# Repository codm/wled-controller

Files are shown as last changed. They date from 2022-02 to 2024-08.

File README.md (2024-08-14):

# cod.m WLED Controller (Wi-FI/WLAN)

ESP32 based WLED Controller Wi-Fi to drive adressable LED strips like Neopixel/WS281x/SK6812/WS2801/WS2815/etc using [WLED](https://github.com/Aircoookie/WLED).
Version 0.8 now can be used with 5V *and* 12V strips without the need of external dc-dc converters and we've updated the microcontroller from an ESP8266 to an ESP32. Therefore handling of more LED's and multiple strips are no problem. See https://kno.wled.ge/features/multi-strip/

There now is a button (`IO15`) which can be freely confirugred via WLED. See https://kno.wled.ge/features/macros/#buttons Theoreticly you can also use the flash button on the PCB as an input (`IO0`).

As of WLED 0.13 the first button can be used to do a factory reset by holding it for longer than ten seconds.

* [Wiring Example WS281x/SK6812 5V/12V/24V](https://shop.codm.de/media/e0/8c/7e/1694690940/wiring-scheme-wled-controller-V0.8-WS281x-SK6812.pdf)
* [Wiring Example WS2801/APA102 5V/12V/24V](https://shop.codm.de/media/15/71/33/1694690940/wiring-scheme-wled-controller-V0.8-WS2801.pdf)
* [Wiring Example WS2815 12V](https://shop.codm.de/media/7c/08/47/1694690940/wiring-scheme-wled-controller-V0.8-WS2815.pdf)

More documentation could be foun in the [cod.m Knowledge Base: WLED Controller](https://docs.codm.de/en/wled/controller/).

You can buy it at our webshop: 
* [WLED Controller (Wi-Fi)](https://shop.codm.de/en/automation/wled/30/wled-controller-wlan/wi-fi) (English)
* [WLED Controller (WLAN)](https://shop.codm.de/automation/pixel/30/wlan-pixel-controller-wled) (German)

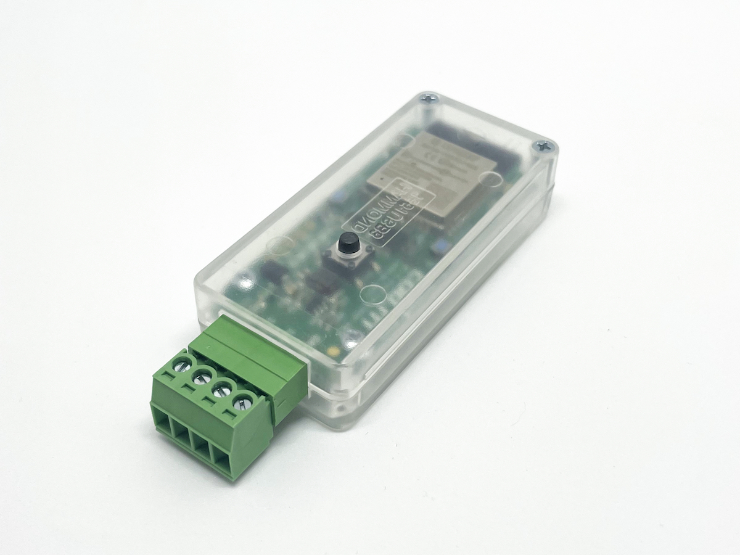
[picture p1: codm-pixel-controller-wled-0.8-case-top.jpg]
cod.m GmbH WLED Controller (Wi-Fi/WLAN) (https://shop.codm.de/automation/wled/30/wled-controller-wlan/wi-fi)


The board comes preflashed with the current version of WLED, but can be used with any firmware you like, as we've added a flash and reset button for easy flashing.

It can be used with nearly every type of adressable led strips: WS2812B, WS2813, SK6812, APA102, WS2801, LPD8806, TM1814, WS2811, WS2815, GS8208.

Please read the [Adafruit Neopixel Uberguide](https://learn.adafruit.com/adafruit-neopixel-uberguide) on how to work with Neopixels. Antother good starting pint is the [WLED documentation](https://kno.wled.ge/).

Based on the LoxPixel-idea from Dennis (www.unser-smartes-zuhause.de) we've discussed a board layout and in the beginning developed our own software based in Dennis' initial code.
In the end we've settled to expand the absolutely astonishing WLED project with the needed features for Loxone. In Version 0.11 WLED can now understand Loxone values.

## Features

* Espressif ESP32-WROOM-32E 4MB
* usable in 5V, 12V and 24V installations
* up to four lanes of pixel
* drives up to 1000 pixel per lane
* more ESP32 pins are accesible on the back of the PCB
* compact (72x30x16mm)
* reverse polarity protection
* wiring through srew-plug terminal
* real 74AHCT125D level shifter
* detailed instructions
* could be easily (re-)programmed
* open source (CC-BY-NC-SA 4.0)

# Thanks

* [Aircookie](https://github.com/Aircoookie) and the folks from [WLED](https://github.com/Aircoookie/WLED)
* Dennis Henning for the inital idea of the [Lox!Pixel](https://unser-smartes-zuhause.de/2019/10/20/loxpixel-rgbw-neopixel-integration-in-loxone/)
* [m0fa](https://github.com/m0fa)

# License

[CC-BY-NC-SA 4.0](https://creativecommons.org/licenses/by-nc-sa/4.0/de/)

cod.m GmbH, Patrik Mayer, 2022

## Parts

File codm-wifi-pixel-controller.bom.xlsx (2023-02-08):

WLED Controller V0.8
Qty | Value | Device | Package | Parts | Description
2 |  | 434153017835 | 434153017835 | FLASH, RESET | WS-TASV J-Bend SMT Tact Switch 3.5x2.9 mm
1 |  | PINHD-1X5 | 1X05 | JP1 | PIN HEADER
4 | 100n | C-EUC0603K | C0603K | C2, C3, C6, C11 | CAPACITOR, European symbol
2 | 10k | R-EU_R0603 | R0603 | R4, R5 | RESISTOR, European symbol
1 | 10u | C-EUC0805K | C0805K | C1 | CAPACITOR, European symbol
1 | 150080RS75000 | LEDCHIP-LED0805 | CHIP-LED0805 | LED | LED
1 | 1u | C-EUC0603K | C0603K | C5 | CAPACITOR, European symbol
3 | 2.2uF | C-EUC0603K | C0603K | C8, C9, C10 | CAPACITOR, European symbol
1 | 22k1 | R-EU_R0603 | R0603 | R2 | RESISTOR, European symbol
2 | 22uF/6.3V/20% | C-EUC0805K | C0805K | C4, C7 | CAPACITOR, European symbol
1 | 24V 500mA | PTCFUSE-1206 | R1206 | F1 | PTC fuses, resettable thermistors
1 | 2k7 | R-EU_R0603 | R0603 | R3 | RESISTOR, European symbol
1 | 3.3uH | WE-LQ_1812_744045003 | WE-LQ_1812 | L1 | WE-LQ SMD Inductor
1 | 330 | 4R-NEXB38V | EXB38V | RN1 | Array Chip Resistor
1 | 430182070816 | 430182070816 | 430182070816 | S1 | WS-TASV SMT Tact Switch 6x6 mm
1 | 69k8 | R-EU_R0603 | R0603 | R1 | RESISTOR, European symbol
1 | AP62XXX-TSOT26 | AP62XXX-TSOT26 | AP62XXX-TSOT26 | U1
1 | ESP-WROOM-32 | ESP-WROOM-32 | ESP-WROOM-32 | U4
1 | MCV-1,5/4-G-3,81 | MCV-1,5/4-G-3,81 | MCV-1,5/4-G-3,81 | U$101
1 | REG710NA-5/250 | REG710NA-5/250 | SOT95P280X145-6N | U2 | Check prices
1 | SK34A | DIODE-DO214AC | DO214AC | D1 | DIODE
1 | SN74AHCT125PWR | SN74AHCT125PWR | SOP65P640X120-14N | U3 | Check availability

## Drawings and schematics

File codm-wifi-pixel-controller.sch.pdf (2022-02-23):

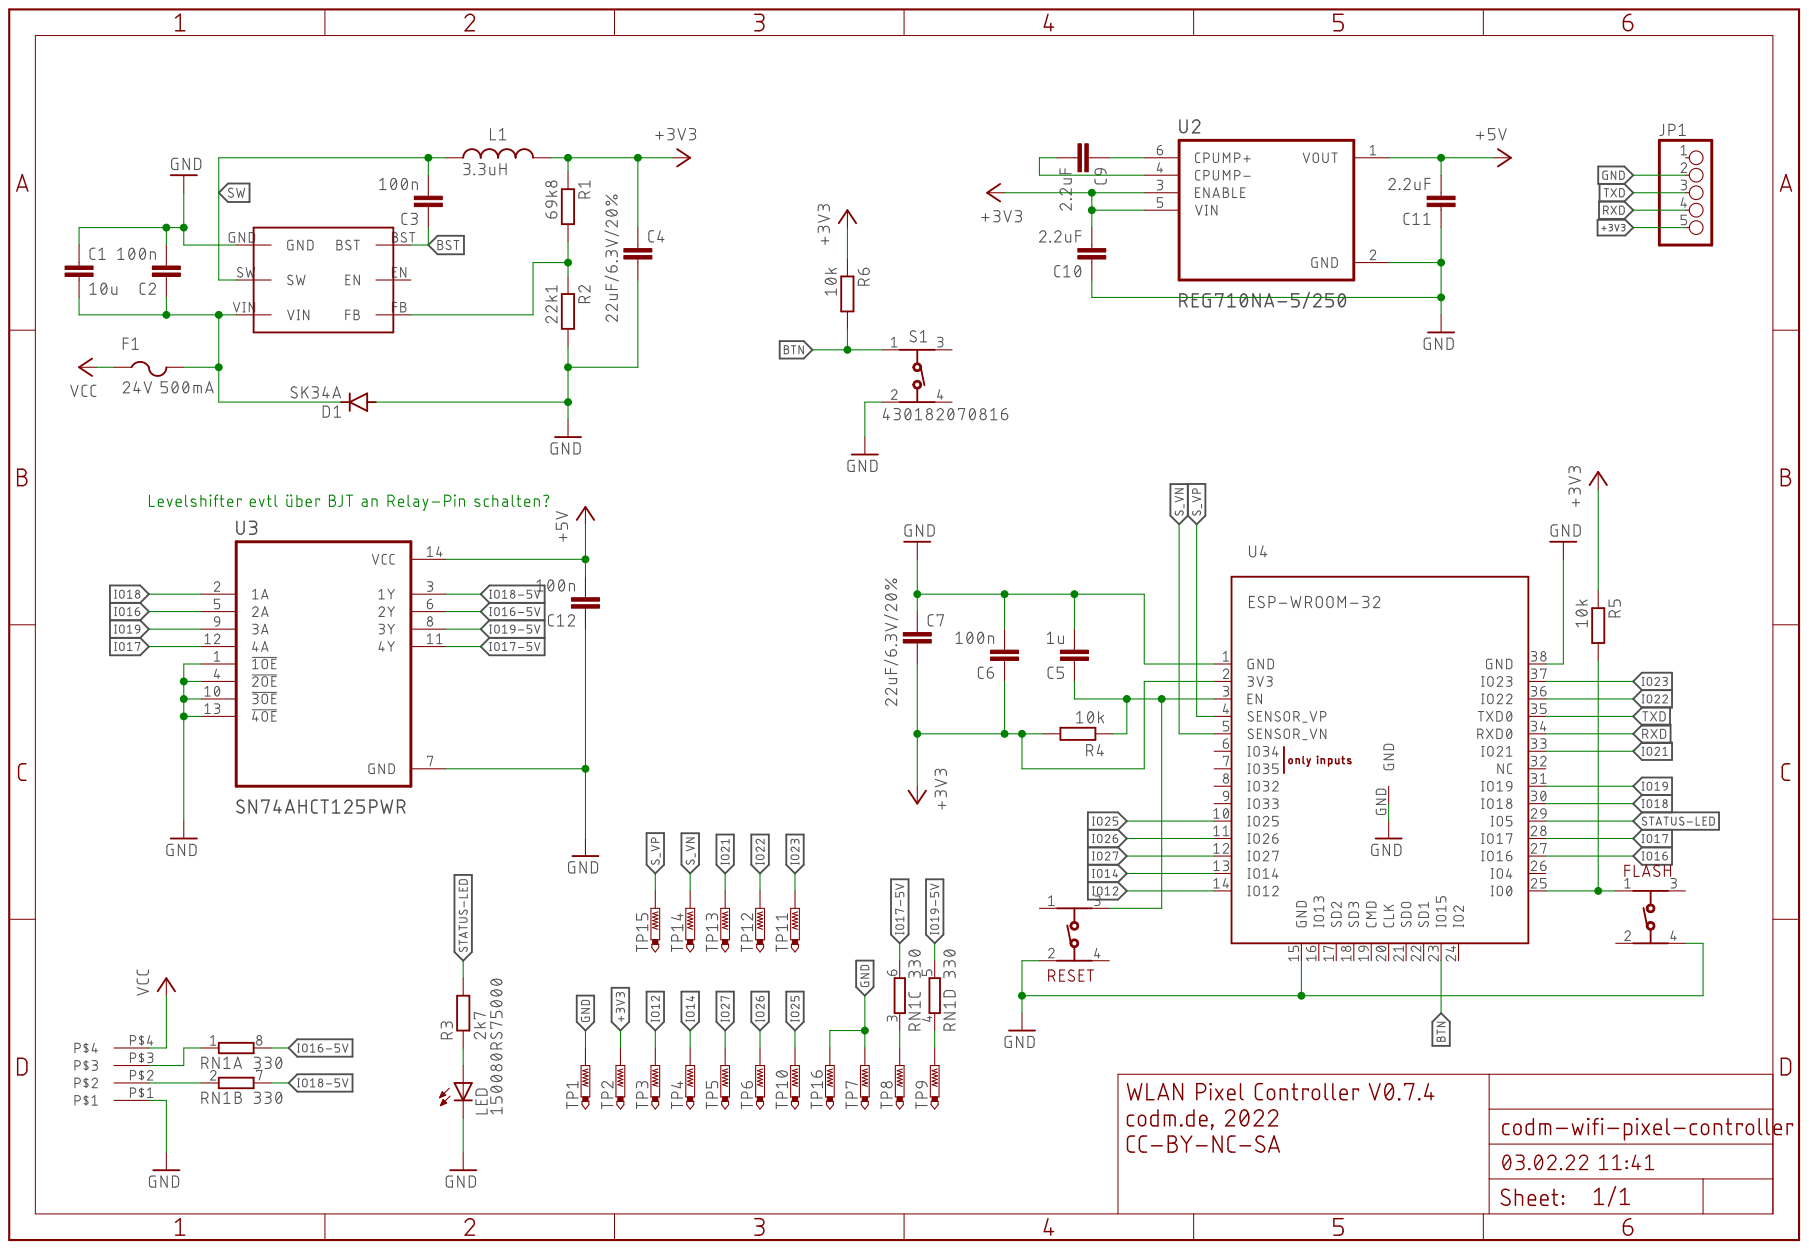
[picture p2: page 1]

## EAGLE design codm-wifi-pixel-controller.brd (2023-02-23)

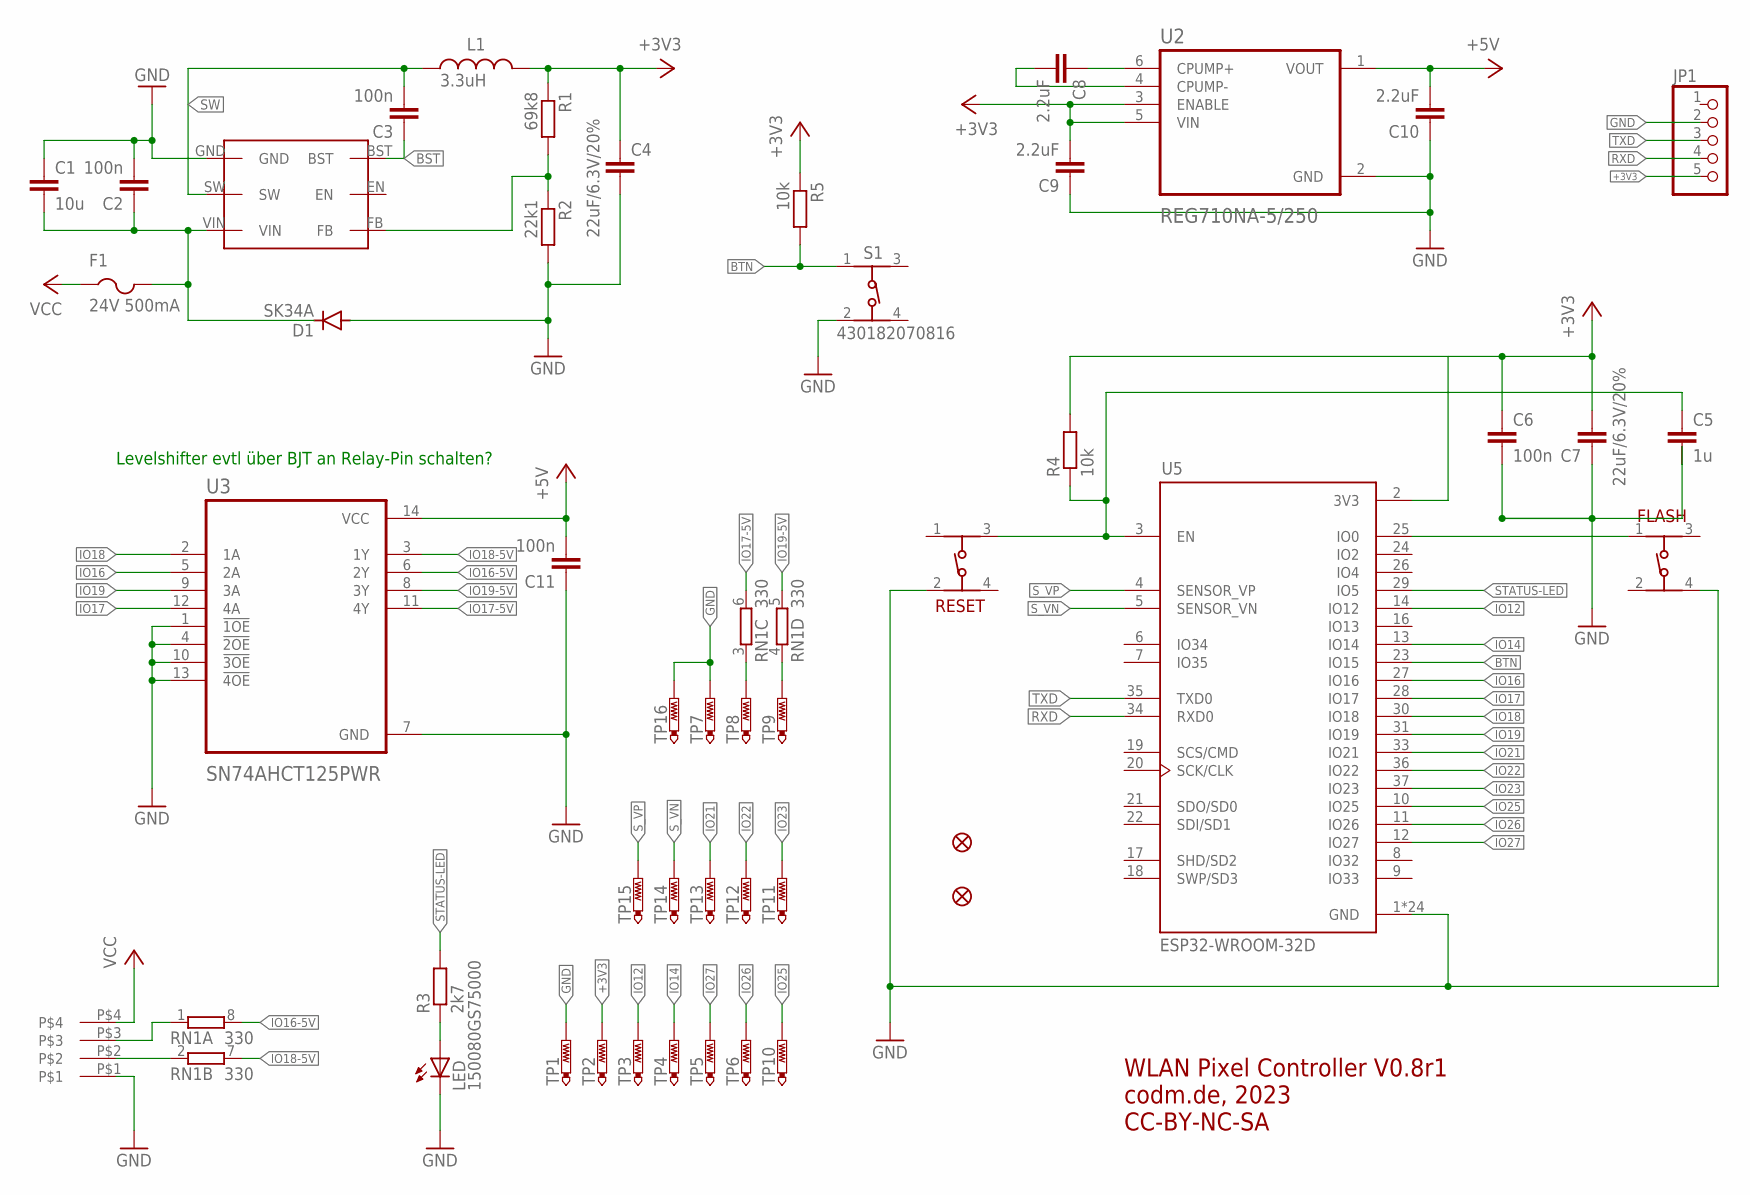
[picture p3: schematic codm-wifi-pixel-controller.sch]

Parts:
C1: 10u; C0805K
C2, C3, C6, C11: 100n; C0603K
C4, C7: 22uF/6.3V/20%; C0805K
C5: 1u; C0603K
C8, C9, C10: 2.2uF; C0603K
D1: SK34A; DO214AC
F1: 24V 500mA; R1206
FD1, FD2: FIDUCIAL1X2; FIDUCIAL-1X2
FLASH: 434153017835
JP1: PINHD-1X5; 1X05
L1: 3.3uH; WE-LQ_1812
LED: 150080GS75000; CHIP-LED0805
R1: 69k8; R0603
R2: 22k1; R0603
R3: 2k7; R0603
R4, R5: 10k; R0603
RESET: 434153017835
RN1: 330; EXB38V
S1: 430182070816
TP1, TP2, TP3, TP4, TP5, TP6, TP7, TP8, TP9, TP10, TP11, TP12, TP13, TP14, TP15, TP16: PTR1TP14R; TP14R
U1: AP62XXX-TSOT26
U2: REG710NA-5/250; SOT95P280X145-6N
U3: SN74AHCT125PWR; SOP65P640X120-14N
U5: ESP32-WROOM-32D; MODULE_ESP32-WROOM-32D
U$101: MCV-1,5/4-G-3,81

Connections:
+3V3: C4.1, C6.1, C7.2, C9.2, JP1.5, L1.2, R1.1, R4.2, R5.1, TP2.TP, U2.3 (ENABLE), U2.5 (VIN), U5.2 (3V3)
+5V: C10.2, C11.2, U2.1 (VOUT), U3.14 (VCC)
BST: C3.1, U1.BST
BTN: R5.2, S1.1, U5.23 (IO15)
GND: C1.1, C2.2, C4.2, C5.2, C6.2, C7.1, C9.1, C10.1, C11.1, D1.A, FLASH.4, JP1.2, LED.C, R2.2, RESET.2 (3), S1.2, TP1.TP, TP7.TP, TP16.TP, U1.GND, U2.2 (GND), U3.1 (!1OE), U3.4 (!2OE), U3.7 (GND), U3.10 (!3OE), U3.13 (!4OE), U5.1 (GND), U5.15 (GND), U5.38 (GND), U5.39_1 (GND), U5.39_2 (GND), U5.39_3 (GND), U5.39_4 (GND), U5.39_5 (GND), U5.39_6 (GND), U5.39_7 (GND), U5.39_8 (GND), U5.39_9 (GND), U5.39_10 (GND), U5.39_11 (GND), U5.39_12 (GND), U5.39_13 (GND), U5.39_14 (GND), U5.39_15 (GND), U5.39_16 (GND), U5.39_17 (GND), U5.39_18 (GND), U5.39_19 (GND), U5.39_20 (GND), U5.39_21 (GND), U$101.P$1
GPIO0: FLASH.1, U5.25 (IO0)
IO12: TP3.TP, U5.14 (IO12)
IO14: TP4.TP, U5.13 (IO14)
IO16: U3.5 (2A), U5.27 (IO16)
IO16-5V: RN1.8 (2), U3.6 (2Y)
IO16-5VR: RN1.1, U$101.P$3
IO17: U3.12 (4A), U5.28 (IO17)
IO17-5V: RN1.6 (2), U3.11 (4Y)
IO17-5VR: RN1.3 (1), TP8.TP
IO18: U3.2 (1A), U5.30 (IO18)
IO18-5V: RN1.7 (2), U3.3 (1Y)
IO18-5VR: RN1.2 (1), U$101.P$2
IO19: U3.9 (3A), U5.31 (IO19)
IO19-5V: RN1.5 (2), U3.8 (3Y)
IO19-5VR: RN1.4 (1), TP9.TP
IO21: TP13.TP, U5.33 (IO21)
IO22: TP12.TP, U5.36 (IO22)
IO23: TP11.TP, U5.37 (IO23)
IO25: TP10.TP, U5.10 (IO25)
IO26: TP6.TP, U5.11 (IO26)
IO27: TP5.TP, U5.12 (IO27)
unnamed: C8.1, U2.6 (CPUMP+)
unnamed: R1.2, R2.1, U1.FB
unnamed: LED.A, R3.1
unnamed: C8.2, U2.4 (CPUMP-)
RESET: C5.1, R4.1, RESET.3 (2), U5.3 (EN)
RXD: JP1.4, U5.34 (RXD0)
STATUS-LED: R3.2, U5.29 (IO5)
SW: C3.2, L1.1, U1.SW
S_VN: TP14.TP, U5.5 (SENSOR_VN)
S_VP: TP15.TP, U5.4 (SENSOR_VP)
TXD: JP1.3, U5.35 (TXD0)
VCC: F1.1, U$101.P$4
VCCF: C1.2, C2.1, D1.C, F1.2, U1.VIN

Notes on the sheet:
WLAN Pixel Controller V0.8r1 codm.de, 2023 CC-BY-NC-SA
Levelshifter evtl über BJT an Relay-Pin schalten?

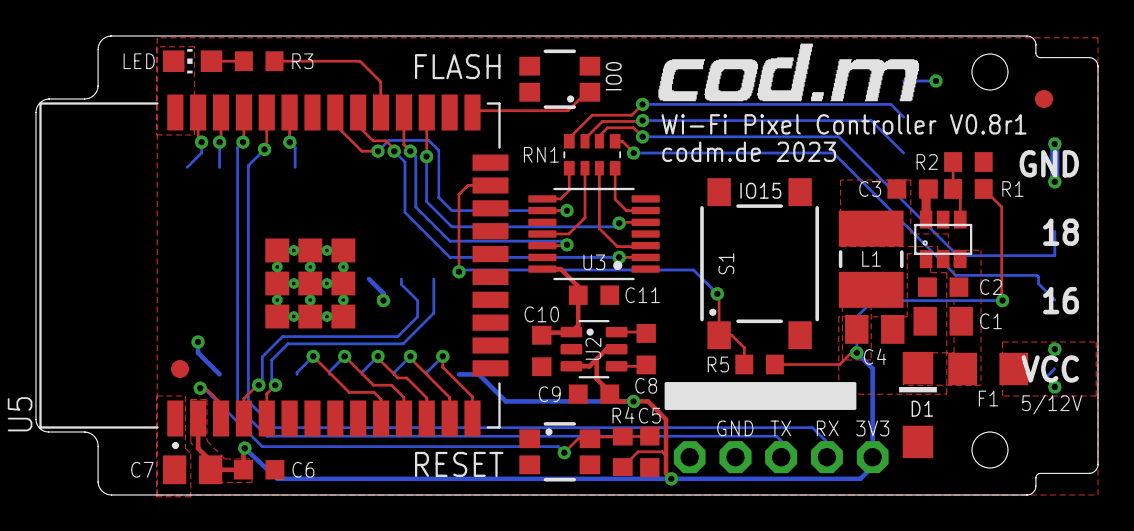
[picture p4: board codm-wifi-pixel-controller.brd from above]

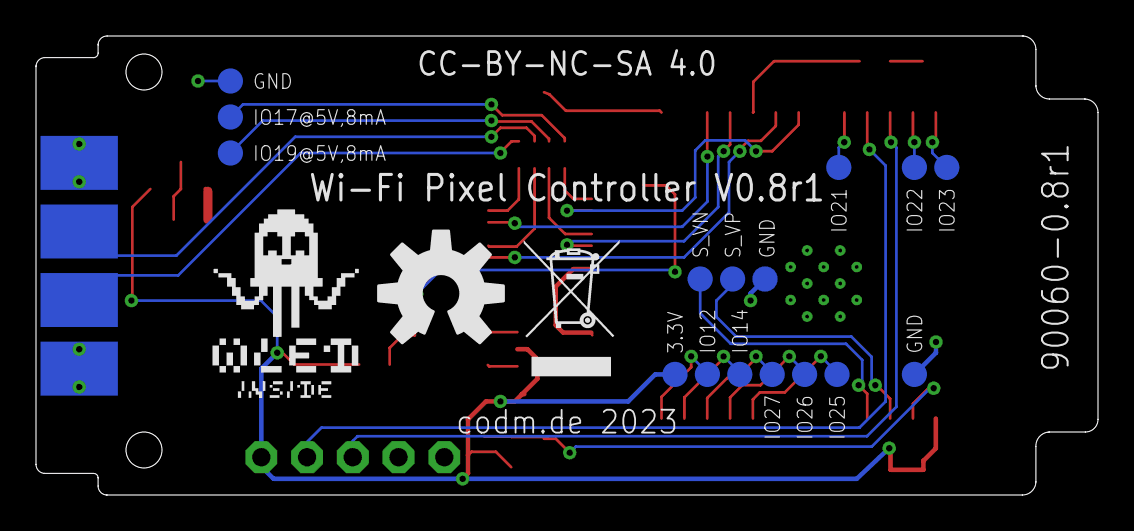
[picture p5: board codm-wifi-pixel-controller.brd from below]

Board: 2 copper layers, 59.0 x 25.5 mm, 52 parts (20 on the bottom side), 39 nets.

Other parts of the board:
U$1: CODM-LOGO
U$2: WLED-INSIDE-LOGO-10MM
U$100: WEEE-LOGO-5MM
U$102: OSHW-LOGO-L

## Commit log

2020-08-11 v 0.4, initial git
    [neopixel-controller-bom.csv, neopixel-controller-bom.xlsx, neopixel-controller.brd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]
2020-09-03 changed 3d model
    [neopixel-controller.brd, neopixel-controller.sch]
2020-09-10 added 74ahct125, rework for v0.5
    [neopixel-controller.brd, neopixel-controller.sch]
2020-09-17 v0.5 pr
    [neopixel-controller.brd, neopixel-controller.sch]
2020-10-26 fixed OE of 74AHCT125
    [neopixel-controller.brd, neopixel-controller.sch]
2020-11-23 minor changes in schematic
    [neopixel-controller-bom.csv, neopixel-controller-bom.xlsx, neopixel-controller.sch]
2020-11-23 added readme, initial github release
    [codm-wifi-pixel-controller.brd, codm-wifi-pixel-controller.sch]
2021-04-12 v0.6 with placeholder for pick&place
    [codm-wifi-pixel-controller.brd, neopixel-controller-bom.csv, neopixel-controller-bom.xlsx]
2021-10-04 development version 0.7
    [codm-wifi-pixel-controller.brd, neopixel-controller-bom.csv]
2021-10-06 version with TLV767 and bigger thermal via/planes
    [codm-wifi-pixel-controller.brd, codm-wifi-pixel-controller.sch]
2021-10-29 prototype 0.7.2
    [codm-wifi-pixel-controller.brd, codm-wifi-pixel-controller.sch]
2022-01-24 V0.7.3 - forgot reverse polarity protection
    [codm-wifi-pixel-controller.bom.xlsx, codm-wifi-pixel-controller.brd, codm-wifi-pixel-controller.sch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]
2022-01-24 added reverse polarity protection
    [codm-wifi-pixel-controller.brd, codm-wifi-pixel-controller.sch]
2022-02-02 new version 0.7.4 with fixes
    [codm-wifi-pixel-controller.brd, codm-wifi-pixel-controller.sch]
2022-02-04 finetuning 0.7.4
    [codm-wifi-pixel-controller.brd, codm-wifi-pixel-controller.sch]
2022-02-23 after prototype 0.7.4 - final 0.8
    [codm-wifi-pixel-controller.bom.csv, codm-wifi-pixel-controller.bom.xlsx, codm-wifi-pixel-controller.brd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]
2022-03-29 final V0.8, edited readme
    [codm-wifi-pixel-controller.brd, codm-wifi-pixel-controller.sch]
2023-02-22 better esp32 footprint, minor rearangements
    [codm-wifi-pixel-controller.brd, codm-wifi-pixel-controller.sch]
2023-02-22 updated year on top
    [codm-wifi-pixel-controller.brd]
2023-02-23 better fiducials
    [codm-wifi-pixel-controller.brd, codm-wifi-pixel-controller.sch]
2023-02-23 fixed groundplane
    [codm-wifi-pixel-controller.brd]
2023-10-18 updated wiring sheme links

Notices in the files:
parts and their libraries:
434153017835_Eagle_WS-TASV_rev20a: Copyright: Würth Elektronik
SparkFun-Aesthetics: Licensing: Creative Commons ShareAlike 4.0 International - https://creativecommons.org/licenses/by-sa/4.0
